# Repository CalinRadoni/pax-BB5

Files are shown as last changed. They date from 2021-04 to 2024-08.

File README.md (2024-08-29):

# PAx BaseBoard STM32L051K8T

The hardware board is the one created by me in 2017, published in [PAx5](https://github.com/CalinRadoni/PAx5) repository. The new addition is PlatformIO compatibility files to allow programming the board with 
Arduino, CMSIS, LibOpenCM3 or STM32Cube frameworks.

See the [docs site](https://calinradoni.github.io/pax-BB5/) for pinout, schematic and more.

## The code

In the `src` directory I have created blink test code for Arduino, CMSIS, LibOpenCM3 and STM32Cube.
The selection between directories is made through `platformio.ini` configuration file.

## Hardware details

- STM32L051K8T MCU
- RFM69HW transceiver module 868MHz
- M25P10 128kB Flash memory
- on-board LED
- on-board switch port

## Development Environment

- [PlatformIO](https://platformio.org) Core, version 5.1.1.
- editing was done in [Visual Studio Code](https://code.visualstudio.com)
- version control with [Git](https://git-scm.com)
- [KiCad EDA](http://kicad.org/) for hardware schematic and PCB board
- [GIMP](https://www.gimp.org/) and [Inkscape](https://inkscape.org/en/) for images

## License

*Unless otherwise specified:*

The software and documentation are released under the [GNU GPLv3](http://www.gnu.org/licenses/gpl-3.0.html) License. See the __LICENSE-GPLv3.txt__ file.

The hardware schematics are licensed under a [Creative Commons Attribution-ShareAlike 4.0 International License](http://creativecommons.org/licenses/by-sa/4.0/).
See the __LICENSE-CC-BY-SA-4.0.txt__ file.

The code for Arduino Variant is:

- Copyright (c) 2021, STMicroelectronics
- Copyright (c) 2021, CalinRadoni (https://github.com/CalinRadoni)

and released under the [BSD 3-Clause license](https://opensource.org/licenses/BSD-3-Clause).

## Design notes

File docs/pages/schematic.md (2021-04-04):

---
title: Schematic for pax-BB5
#description: 
date: 2021-04-04
#date-modified: 
---

Schematic

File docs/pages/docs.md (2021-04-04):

---
title: Documentation for pax-BB5
#description: 
date: 2021-04-04
#date-modified: 
---

## Sorry, this is really work-in-progress, just some thin information for now

- [Pinout]({{ site.baseurl }}{% link pages/pinout.md %})
- [Schematic]({{ site.baseurl }}{% link pages/schematic.md %})
- [Usage with PlatformIO and Arduino, CMSIS, STM32Cube and LibOpenCM3 frameworks]({{ site.baseurl }}{% link pages/platformio.md %})

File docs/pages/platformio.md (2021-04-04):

---
title: Usage with PlatformIO and Arduino, CMSIS, STM32Cube and LibOpenCM3 frameworks
#description: 
date: 2021-04-04
#date-modified: 
---

To install PlatformIO Core see the post [PlatformIO Core](https://calinradoni.github.io/pages/210403-platformiocli.html).

To use this board with PlatformIO see the post
[Custom STM32 board for PlatformIO and Arduino, CMSIS, STM32Cube and LibOpenCM3](https://calinradoni.github.io/pages/210403-platformio-customstm32board.html).

- to compile the all the *blinky* examples execute `pio run`
- to compile only the Arduino example execute `pio run --environment pax_bb5_a`
- to upload the Arduino example execute `pio run --environment pax_bb5_a --target upload`
- to clean up the build files execute `pio run --target clean`

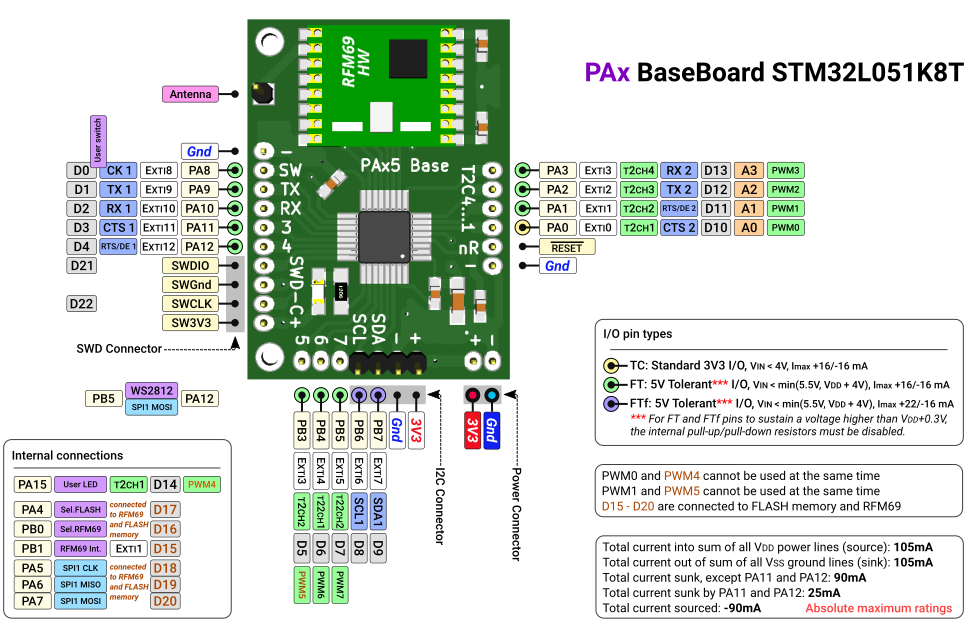
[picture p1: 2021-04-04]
docs/assets/img/pax-BB5-Pinout.png

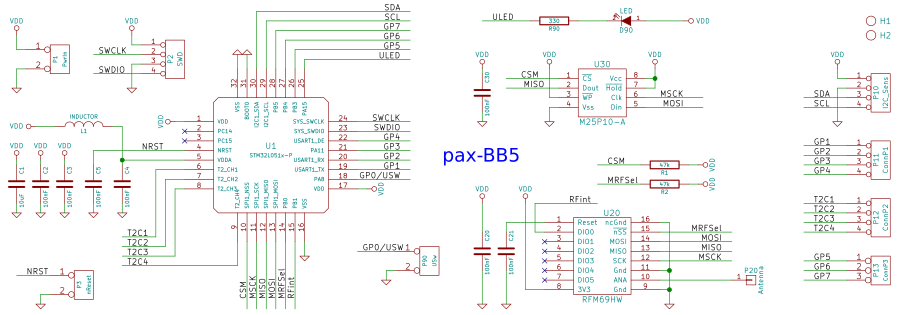
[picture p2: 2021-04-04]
docs/assets/img/pax-BB5-sch.png

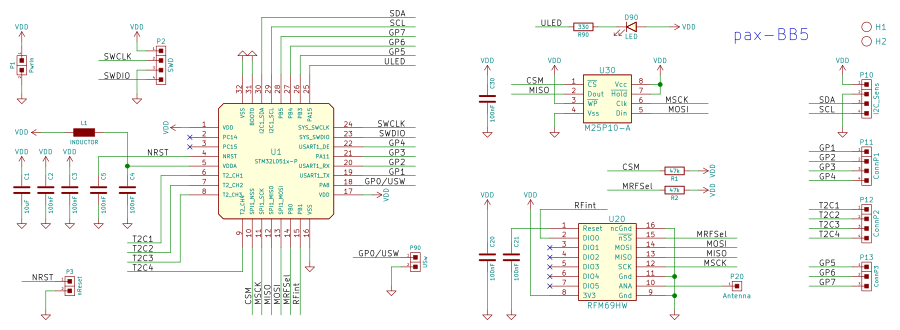
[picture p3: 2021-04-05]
images/pax-BB5-sch.png

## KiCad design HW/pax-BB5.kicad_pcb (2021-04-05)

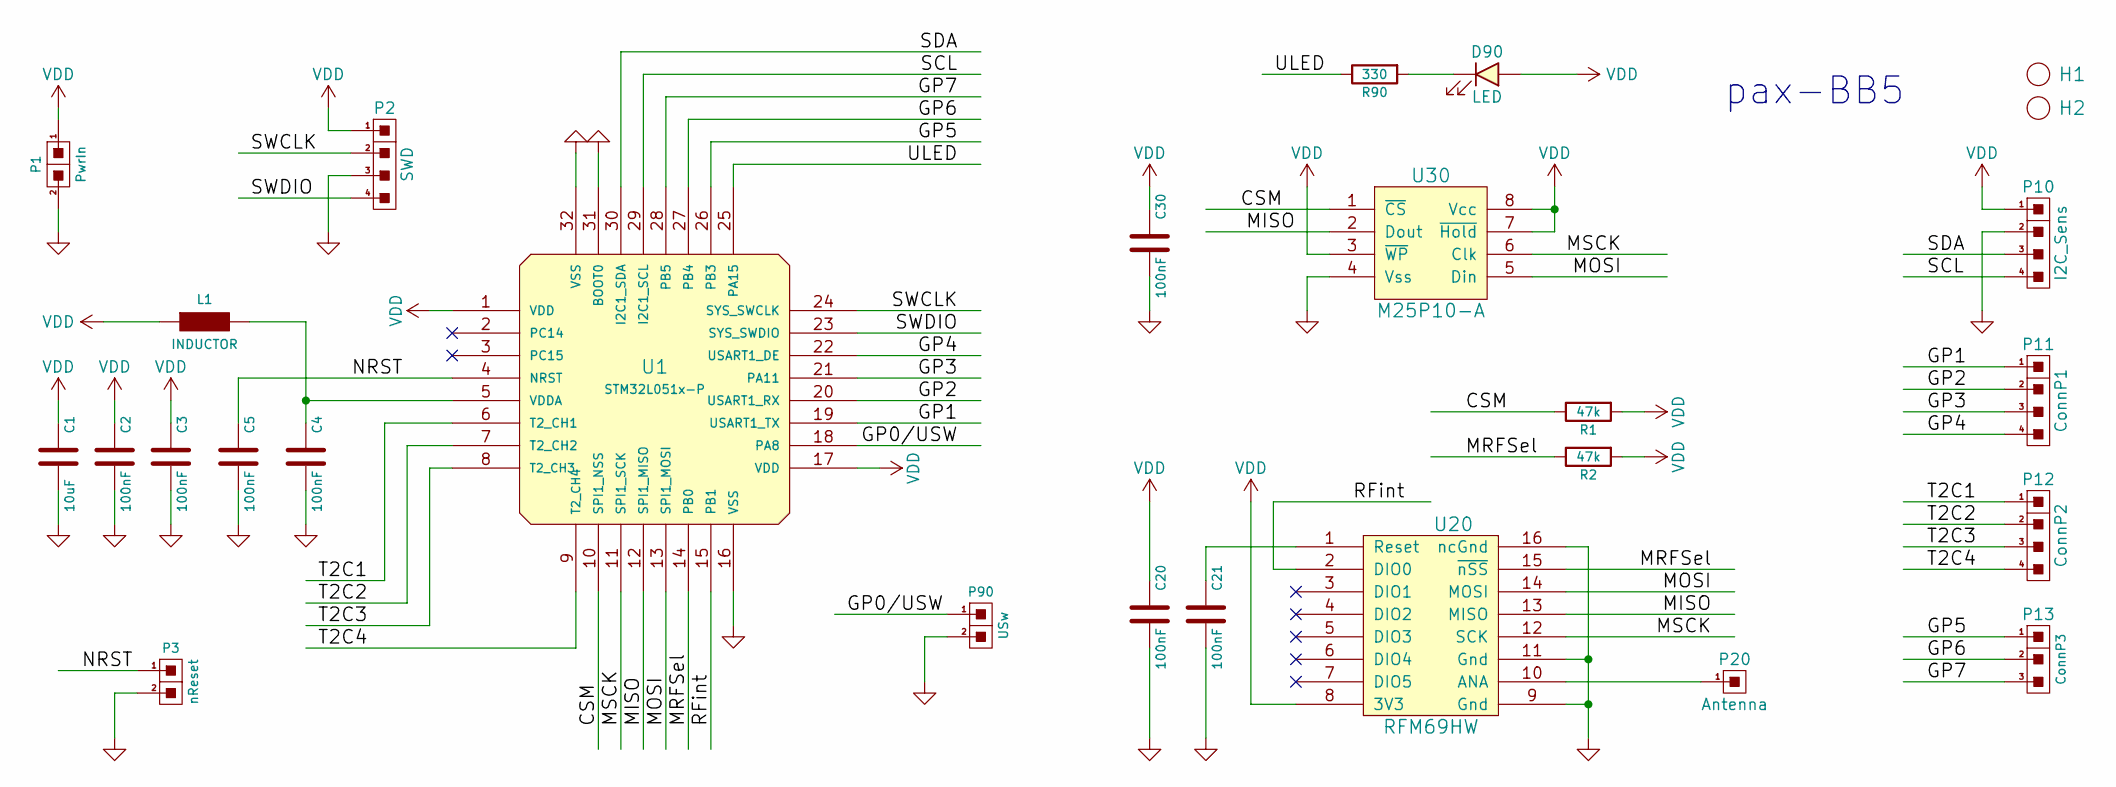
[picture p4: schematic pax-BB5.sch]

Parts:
C1: 10uF; C_1206_HandSoldering
C2, C3, C4, C5, C20, C21, C30: 100nF; C_0805_HandSoldering
D90: LED; LED_1206_HandSoldering
H1, H2: Hole; cHole
L1: INDUCTOR; R_1206_HandSoldering
P1: PwrIn; Pin_Header_Straight_1x02
P2: SWD; Pin_Header_Straight_1x04
P3: nReset; Pin_Header_Straight_1x02
P10: I2C_Sens; Pin_Header_Straight_1x04
P11: ConnP1; Pin_Header_Straight_1x04
P12: ConnP2; Pin_Header_Straight_1x04
P13: ConnP3; Pin_Header_Straight_1x03
P20: Antenna; Pin_Header_Straight_1x01
P90: USw; Pin_Header_Straight_1x02
R1, R2: 47k; R_0805_HandSoldering
R90: 330; R_1206_HandSoldering
U1: STM32L051x-P; cLQFP32-7
U20: RFM69HW
U30: M25P10-A; SOIC-8-N

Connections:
/CSM: R1.2, U1.10 (SPI1_NSS), U30.1 (~CS)
/GP0/USW: P90.1, U1.18 (PA8)
/GP1: P11.1, U1.19 (USART1_TX)
/GP2: P11.2, U1.20 (USART1_RX)
/GP3: P11.3, U1.21 (PA11)
/GP4: P11.4, U1.22 (USART1_DE)
/GP5: P13.1, U1.26 (PB3)
/GP6: P13.2, U1.27 (PB4)
/GP7: P13.3, U1.28 (PB5)
/MISO: U1.12 (SPI1_MISO), U20.13 (MISO), U30.2 (Dout)
/MOSI: U1.13 (SPI1_MOSI), U20.14 (MOSI), U30.5 (Din)
/MRFSel: R2.2, U1.14 (PB0), U20.15 (~nSS)
/MSCK: U1.11 (SPI1_SCK), U20.12 (SCK), U30.6 (Clk)
/NRST: C5.1, P3.1, U1.4 (NRST)
/RFint: U1.15 (PB1), U20.2 (DIO0)
/SCL: P10.4, U1.29 (I2C1_SCL)
/SDA: P10.3, U1.30 (I2C1_SDA)
/SWCLK: P2.2, U1.24 (SYS_SWCLK)
/SWDIO: P2.4, U1.23 (SYS_SWDIO)
/T2C1: P12.1, U1.6 (T2_CH1)
/T2C2: P12.2, U1.7 (T2_CH2)
/T2C3: P12.3, U1.8 (T2_CH3)
/T2C4: P12.4, U1.9 (T2_CH4)
/ULED: R90.2, U1.25 (PA15)
GND: C1.2, C2.2, C3.2, C4.2, C5.2, C20.2, C21.2, C30.2, P1.2, P2.3, P3.2, P10.2, P90.2, U1.16 (VSS), U1.31 (BOOT0), U1.32 (VSS), U20.9 (Gnd), U20.11 (Gnd), U20.16 (ncGnd), U30.4 (Vss)
unnamed: C4.1, L1.2, U1.5 (VDDA)
unnamed: C21.1, U20.1 (Reset)
unnamed: D90.K, R90.1
unnamed: P20.1, U20.10 (ANA)
VDD: C1.1, C2.1, C3.1, C20.1, C30.1, D90.A, L1.1, P1.1, P2.1, P10.1, R1.1, R2.1, U1.1 (VDD), U1.17 (VDD), U20.8 (3V3), U30.3 (~WP), U30.7 (~Hold), U30.8 (Vcc)

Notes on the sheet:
pax-BB5

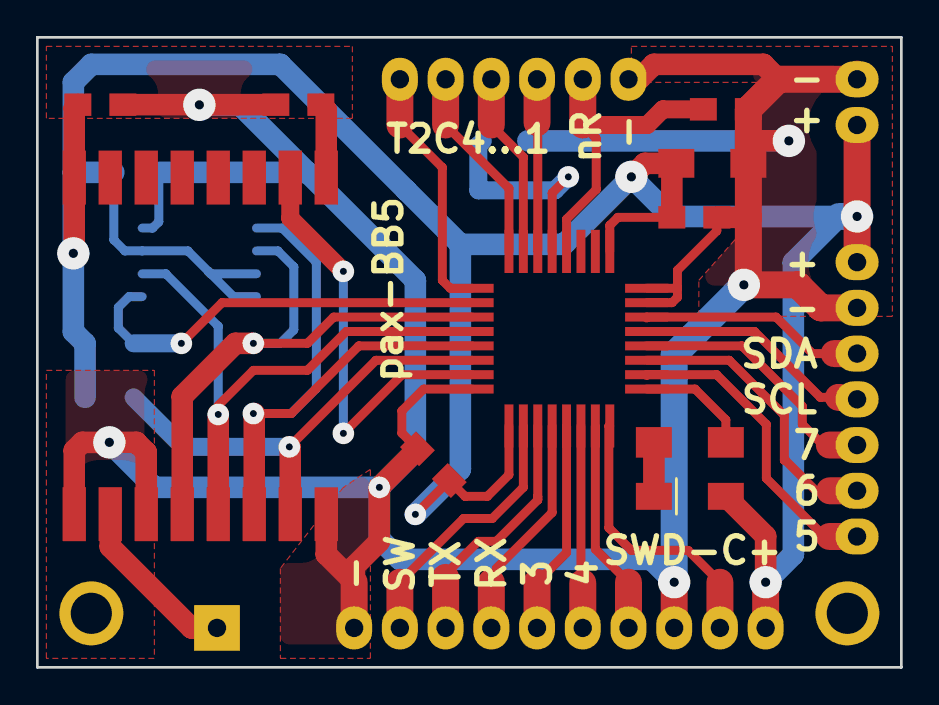
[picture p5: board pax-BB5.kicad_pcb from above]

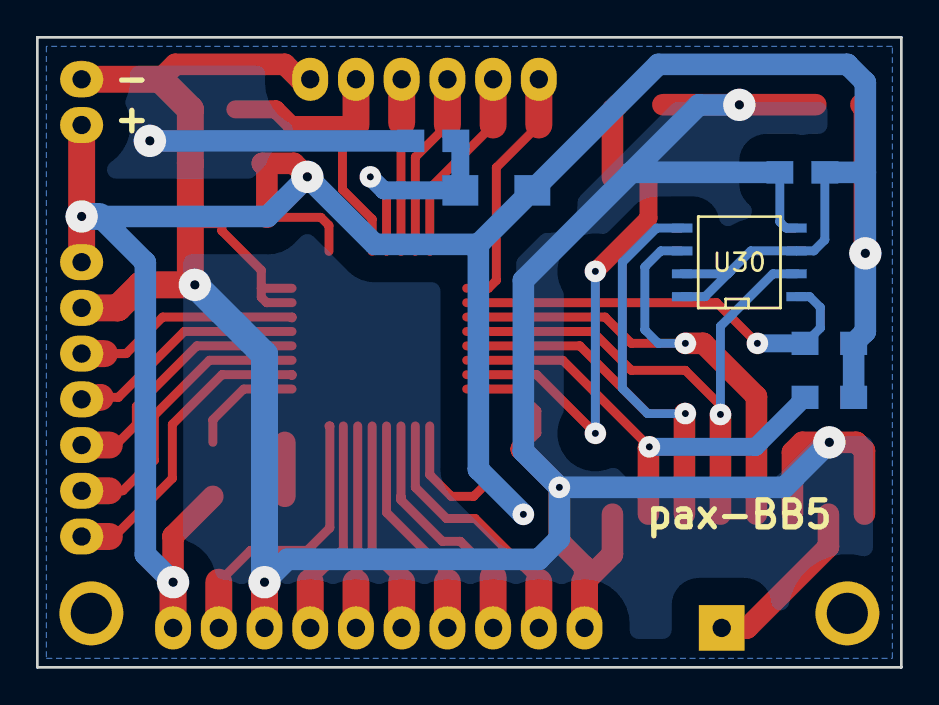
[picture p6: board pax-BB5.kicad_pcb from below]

Board: 2 copper layers, 48.0 x 35.0 mm, 27 parts (13 on the bottom side), 30 nets.

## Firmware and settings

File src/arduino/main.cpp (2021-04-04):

/**
This file is part of pax-BB5 (https://github.com/CalinRadoni/pax-BB5)
Copyright (C) 2021 by Calin Radoni

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
You should have received a copy of the GNU General Public License
along with this program.  If not, see <http://www.gnu.org/licenses/>.
*/

#include "Arduino.h"

void setup()
{
    // set LED_BUILTIN as output
    pinMode(LED_BUILTIN, OUTPUT);
}

void loop()
{
    // LED_BUILTIN reset (LED on)
    digitalWrite(LED_BUILTIN, LOW);
    delay(300);

    // LED_BUILTIN set (LED off)
    digitalWrite(LED_BUILTIN, HIGH);
    delay(600);
}

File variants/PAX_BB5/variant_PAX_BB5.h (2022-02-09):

/*
 *******************************************************************************
 * Copyright (c) 2021, STMicroelectronics
 * All rights reserved.
 *
 * This software component is licensed by ST under BSD 3-Clause license,
 * the "License"; You may not use this file except in compliance with the
 * License. You may obtain a copy of the License at:
 *                        opensource.org/licenses/BSD-3-Clause
 *
 *******************************************************************************
 *
 * Copyright (c) 2021, CalinRadoni (https://github.com/CalinRadoni)
 *
 * This file is part of PAX_BB5 Arduino Variant (https://github.com/CalinRadoni/pax-BB5)
 * Original file was heavily modified for pax-BB5 board (STM32L051K8T MCU)
 * Guidelines from https://github.com/stm32duino/Arduino_Core_STM32/tree/main/variants/STM32L0xx/L051K(6-8)T
 *
 *******************************************************************************
 */

#ifndef _VARIANT_ARDUINO_STM32_
#define _VARIANT_ARDUINO_STM32_

#ifdef __cplusplus
extern "C" {
#endif // __cplusplus

/**
 * @brief Returns the exit code generated by calling SystemClock_Config
 *
 * The SystemClock_Config function will set an exit code with the bits as follow:
 * - bit 0 set = function was called
 * - bit 1 set = HAL_RCC_OscConfig execution error
 * - bit 2 set = HAL_RCC_ClockConfig execution error
 * - bit 3 set = HAL_RCCEx_PeriphCLKConfig execution error
 */
unsigned char SystemClock_Config_ExitCode(void);

/*----------------------------------------------------------------------------
 * STM32 pins
 *----------------------------------------------------------------------------*/

#define PA8   0  // User switch
#define PA9   1  // USART1 Tx
#define PA10  2  // USART1 Rx
#define PA11  3
#define PA12  4
#define PB3   5
#define PB4   6
#define PB5   7
#define PB6   8  // SCL
#define PB7   9  // SDA
#define PA0   A0 // ADC_IN0, T2C1
#define PA1   A1 // ADC_IN1, T2C2
#define PA2   A2 // ADC_IN2, T2C3
#define PA3   A3 // ADC_IN3, T2C4
#define PA15  14 // User LED
#define PB1   15 // IntRadio
#define PB0   16 // CSRadio
#define PA4   17 // CSMemory
#define PA5   18 // SPI1_SCK
#define PA6   19 // SPI1_MISO
#define PA7   20 // SPI1_MOSI
#define PA13  21 // SWDIO
#define PA14  22 // SWCLK
// PC14 not connected
// PC15 not connected

#define NUM_DIGITAL_PINS        23
#define NUM_ANALOG_INPUTS       4

// On-board LED pin number
#define LED_BUILTIN             PA15

// On-board user button
#define USER_BTN                PA8

// IRQ from RFM module
#define PIN_IRQ_Radio           PB1

// SPI definitions
#define PIN_SPI_SS_Mem          PA4
#define PIN_SPI_SS_Radio        PB0
#define PIN_SPI_SCK             PA5
#define PIN_SPI_MISO            PA6
#define PIN_SPI_MOSI            PA7
#define PIN_SPI_SS              PA4
#define PIN_SPI_SS1             PB0

// I2C definitions
#define PIN_WIRE_SDA            PB7
#define PIN_WIRE_SCL            PB6

// UART Definitions
#define SERIAL_UART_INSTANCE    1
// Default pin used for generic 'Serial' instance, mandatory for Firmata
#define PIN_SERIAL_RX           PA10
#define PIN_SERIAL_TX           PA9

// Timer Definitions
// Available timers are:
//    LPTIM1
//    TIM2 usable for (PA0, PA1, PA2 and PA3) or (PA15 and PB3)
//    TIM6
//    TIM21
//    TIM22 usable for PB4 and PB5
// Use TIM6/TIM7 when possible as servo and tone don't need GPIO output pin
#define TIMER_TONE              TIM6
#define TIMER_SERVO             TIM21

#ifdef __cplusplus
}
#endif

/*----------------------------------------------------------------------------
 * Arduino objects - C++ only
 *----------------------------------------------------------------------------*/

#ifdef __cplusplus
  // These serial port names are intended to allow libraries and architecture-neutral
  // sketches to automatically default to the correct port name for a particular type
  // of use.  For example, a GPS module would normally connect to SERIAL_PORT_HARDWARE_OPEN,
  // the first hardware serial port whose RX/TX pins are not dedicated to another use.
  //
  // SERIAL_PORT_MONITOR        Port which normally prints to the Arduino Serial Monitor
  //
  // SERIAL_PORT_USBVIRTUAL     Port which is USB virtual serial
  //
  // SERIAL_PORT_LINUXBRIDGE    Port which connects to a Linux system via Bridge library
  //
  // SERIAL_PORT_HARDWARE       Hardware serial port, physical RX & TX pins.
  //
  // SERIAL_PORT_HARDWARE_OPEN  Hardware serial ports which are open for use.  Their RX & TX
  //                            pins are NOT connected to anything by default.
  #define SERIAL_PORT_MONITOR       Serial
  #define SERIAL_PORT_HARDWARE      Serial
  #define SERIAL_PORT_HARDWARE_OPEN Serial
#endif

#endif /* _VARIANT_ARDUINO_STM32_ */

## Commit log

2021-04-04 Adds the board and variant files for this board
2021-04-04 Adds platformio.ini for multiple frameworks
2021-04-05 Adds the updated KiCad project
    [pax-BB5.kicad_pcb, pax-BB5.sch]
2021-04-05 Updates the schematic image
2021-11-08 Update README.md
    https://forum.kicad.info/t/warning-avoid-all-links-to-kicad-pcb-org-use-kicad-org/31521
2022-02-09 Rename some variant files for compatibility with ST STM32 (15.2.0) with framework-arduinoststm32 4.20100.211028 (2.1.0)
2022-02-09 Add useful 'define' and information about timers

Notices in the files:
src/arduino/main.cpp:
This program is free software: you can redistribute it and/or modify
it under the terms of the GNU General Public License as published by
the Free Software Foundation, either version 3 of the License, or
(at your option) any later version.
